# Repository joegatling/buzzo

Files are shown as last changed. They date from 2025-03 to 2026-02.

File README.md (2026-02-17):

# Buzzo

Buzzo Hero Image
Buzzo is a DIY open source set of game show buttons.

# Making A Buzzo Set
For instructions on how to build your own Buzzo can be found [here](/docs/Button_Assembly.md).

# How to Use
Buzzo is a set of buttons for running a fast paced answering game. Each contestant can hit their button to "buzz in". The system will queue up buttons in the order in which they buzzed. Each button is then given 30 seconds to provide an answer. With a set of Buzzo buttons, a standard game of _Trivial Pursuit_ can be turned into an exciting gameshow. 

Buzzo uses a wireless technology called ESP-Now. This allows them to communicate without the need for an existing WiFi network. However, only one Buzzo set can be operating in an area at a time, as all devices will try to communicate to any available controlelr that they can find.

## Buzzo Button

### Power
- Press the button on the Buzzo to turn it on. 
- Press and hold to turn it off.

A Buzzo Button will switch off automatically if left idle for a few minutes.

### Answering
To answer a question, press the button.  This will add the button into a queue, and each button will have 30 seconds to answer before moving to the next button in the queue.
If the timer expires, the device turns **red** and the button cannot be buzzed until the controller resets the round.

When it is a particular Buzzo's turn to answer, the button will light up yellow. As the timer expires, wedges of the button will go dark. Once they are all dark, the turn is over.

Buzzo devices that are in the answer queue will show a blue light. The number of bright wedges indicates device's place in the queue (eg, one bright wedge means 1st in the queue, two bright wedges means 2nd, etc...).

### Scoring
Each button will automatically keep track of correct answers, and display them as wedges on the button. Once a device has accumulated 6 correct answers, it has won.

## Buzzo Controller
The controller has four buttons:

`↺`/`⏻` - Power and Reset  
`⛌` - Incorrect  
`✓` - Correct  
`⃦`- Pause  

### Power
- Press this to turn on the device
- If the device is already powered on, press this to reset current round. This cleares

The Buzzo Controller will switch of automatically afer 15 minutes if there are devices connected, or after 2 minutes if nothing is connected.  
**WARNING: The Buzzo Controller is responsible for keeping track of scores. If it powers off, all devices will reset their score.**

### Judging Questions
If a Buzzo Button is answering, press the button marked `⛌` to judge the answer **incorrect**. Use `✓` to mark the answer as **correct**.
If a previously judged answer needs to be changed, press and hold either `⛌` or `✓`. This will retroactively change the last response.

### Pausing the Countdown
If for any reason the answering countdown needs to be paused (eg, if there is a dispute over a response, or an interruption to play), then hold the pause button. For as long as the button is held, the timer will be paused.

### Reseting
Press the `↺` button to reset the round. This will clear the answer queue, and reset all buttons so that they are ready for the next question.  
After resetting a round, the `↺` button can be pressed and held in order to reset the entire game. This will reset all the scores on all buttons.
Finally, after resetting around the `↺` button can be pressed and held once more to turn off the controller and all devices.

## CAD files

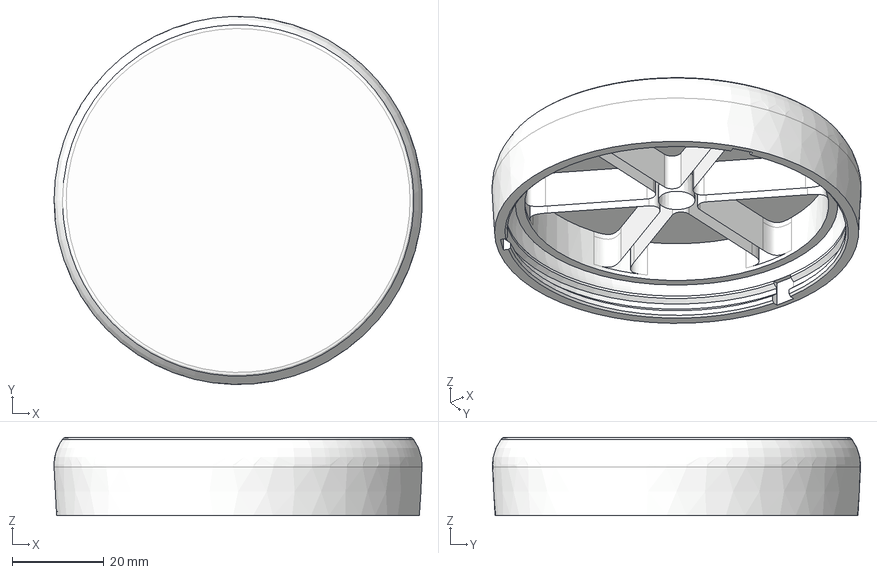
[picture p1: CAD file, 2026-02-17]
3d/Button/Button_ButtonCap_TPU.step
80.1 x 80.1 x 17.0 mm

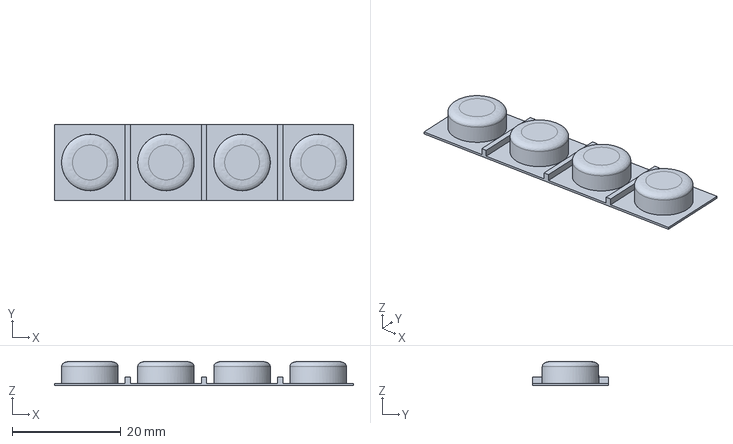
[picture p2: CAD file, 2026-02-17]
3d/Controller/Controller_ButtonCaps_TPU.step
55.0 x 14.0 x 4.50 mm

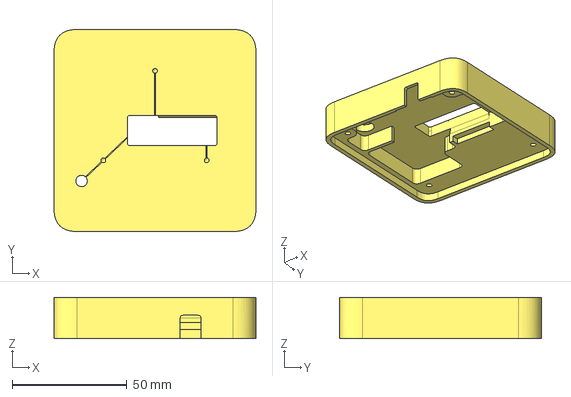
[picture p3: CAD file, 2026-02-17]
3d/Button/Button_Base.step
88.0 x 88.0 x 18.0 mm

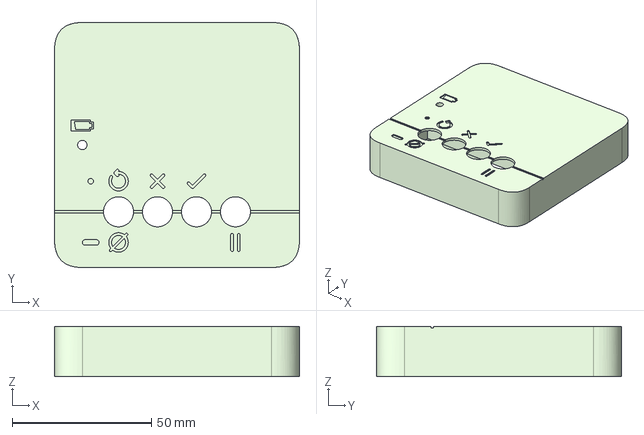
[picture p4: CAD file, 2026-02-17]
3d/Controller/Controller_Base.step
88.0 x 88.0 x 18.0 mm

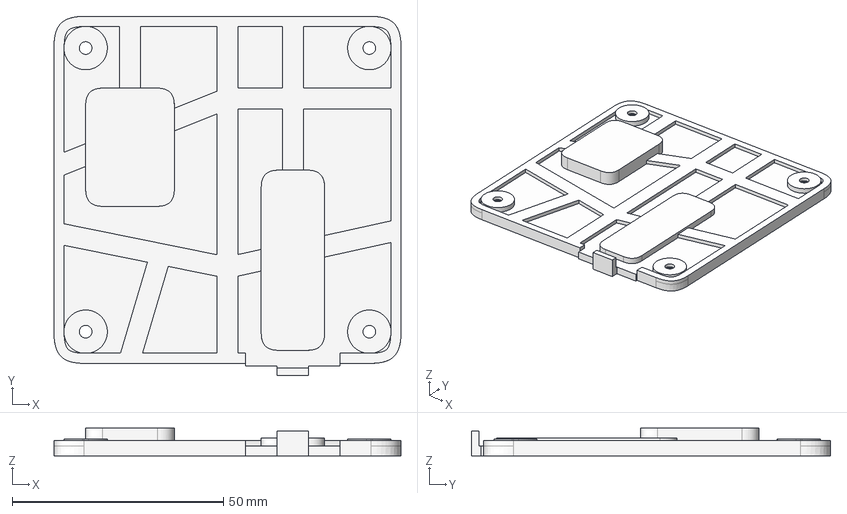
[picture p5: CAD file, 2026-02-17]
3d/Button/Button_Bottom.step
82.2 x 85.1 x 6.60 mm

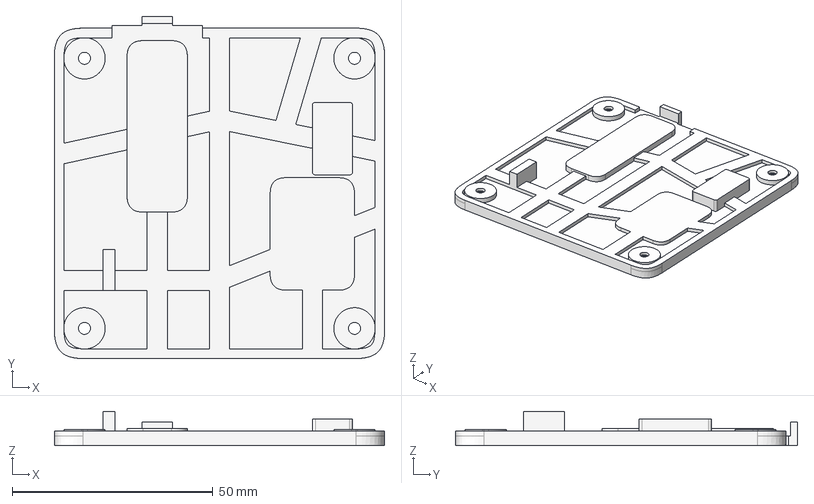
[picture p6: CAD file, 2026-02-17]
3d/Controller/Controller_Bottom.step
82.2 x 85.1 x 8.48 mm

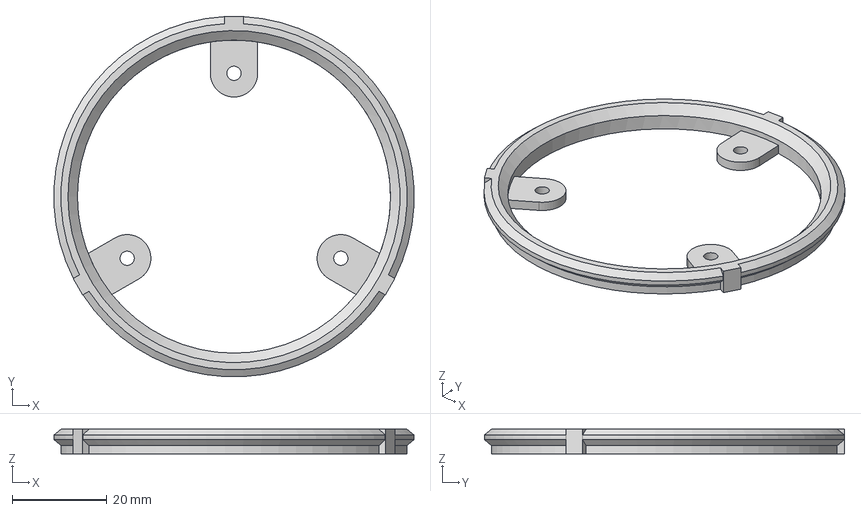
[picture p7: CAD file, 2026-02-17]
3d/Button/Button_Collar.step
75.9 x 75.9 x 5.23 mm

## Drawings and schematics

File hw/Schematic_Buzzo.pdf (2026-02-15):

Button - LEDs | Button - Connections

## GND

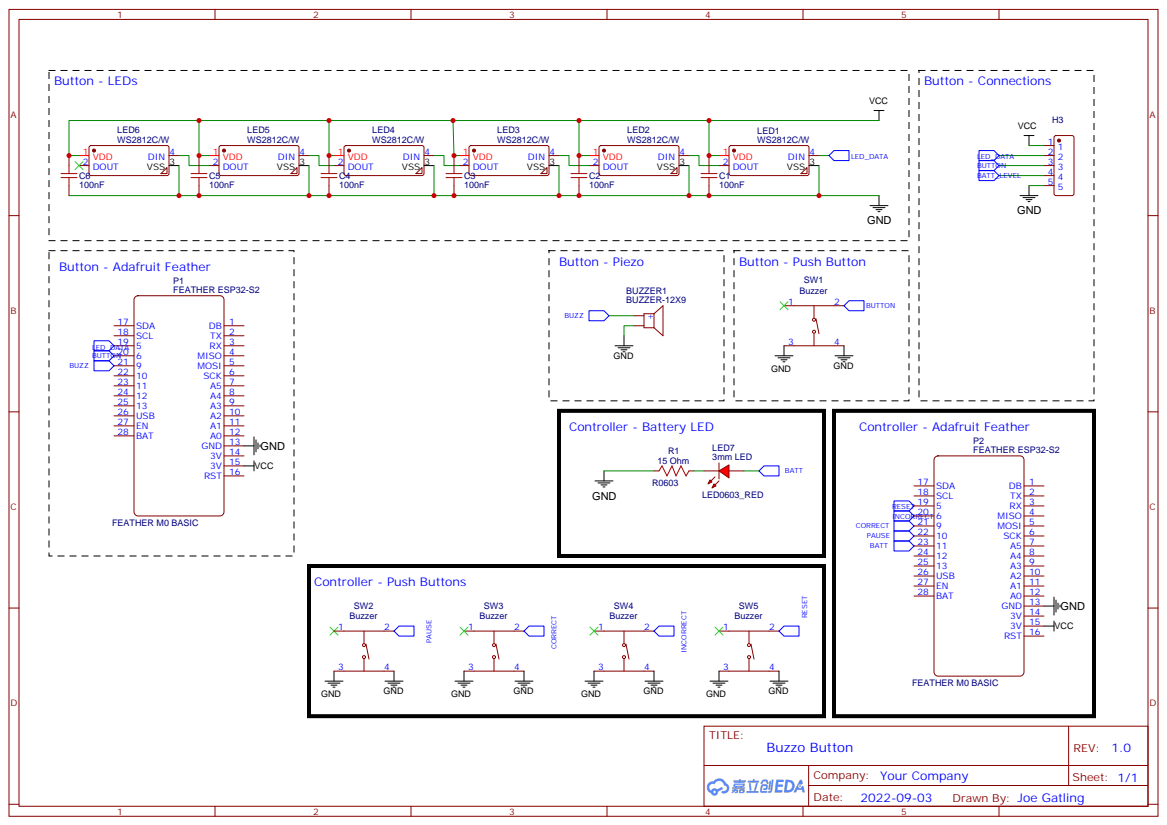
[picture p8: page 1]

Drawn By: Joe Gatling

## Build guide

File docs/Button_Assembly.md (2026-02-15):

# Making a Buzzo

Here's a basic guide for building a Buzzo. 

## Making the Buzzo Button

## Step 1 - Gather the parts
A single Buzzo Button requires...

- 1x Assembled Buzzo LED ring PCB (See step 2)
- 3D printed parts (See Step 3)
- 1x Adafruit ESP32-S3 Feather dev board (https://www.adafruit.com/product/5477)
- 1x 9mm Piezeo Buzzer (https://www.amazon.com/dp/B0827DS4HH)
- 1x 500mAh Lithium Ion Battery (https://www.adafruit.com/product/1578)
- 1x 10mm (tall) x 12mm x 12mm tactile switch (https://www.lcsc.com/product-detail/C127505.html)
- 7x M2x10mm screws
- Wire

## Step 2 - Ordering the PCBs
The main component of the Buzzo Button is a custom LED ring PCB. The gerber files can be found [here](/hw/). My initial run of PCBs were ordered from JLCPCB.com.
The LED ring PCB.

## Step 3 - 3D Print the Parts

All the STEP files for 3D printing can be found [here](/3d/Button/). Most of the parts can be printed out of any kind of PLA but the part `Button_ButtonCap_TPU.step` needs to be printed in white TPU as it needs to be flexible and diffuse light.

## Step 4 - Assemble the wiring
The wiring is quite simple. Connect everything up as follows:

- Feather `3V` ↔ `3.3v` on Ring PCB
- Feather `GND` ↔ `GND` on Ring PCB
- Feather `Pin 5` ↔ `LED` on Ring PCB
- Feather `Pin 6` ↔ `BTN` on Ring PCB
- Feather `Pin 9` ↔ Piezo Pin A (This component has no polarity)
- Feather `GND` ↔ Piezo Pin B (Or `GND` on the Ring PCB)

Example completed Buzzo wiring

All the wiring can be done before assembling the 3D printed parts. Below is what a partially assembled device looks like. 

Some tips:
- Feed the assembled wiring in through the top by sliding the Feather through the hole.
- Note that the LED PCB sits on top of the printed collar piece.
- A small blob of hot glue can be used to hold the piezo speaker in place.

Buzzo button top
Buzzo button top

## Step 5 - Upload the firmware
The firmware is written in C++, and is crea

1. Clone this repo to your computer
2. Install Visual Studio Code
3. Inside Visual Studio Code, install the PlatformIO Add-on
4. Open the project in Visual Studio Code, and set the environment to **buzzo_button_adafruit_USBc**.
5. Plug in your assembled Buzzo Button
6. Click **->** (PlatformIO: Upload)

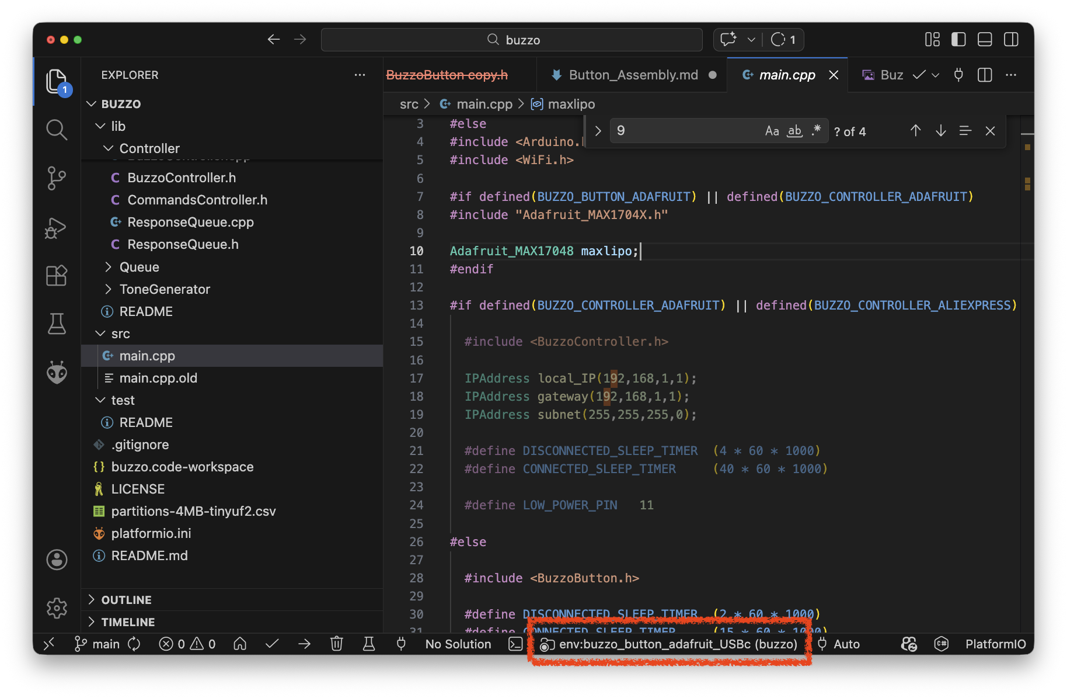
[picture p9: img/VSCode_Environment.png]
Visual studio code environment

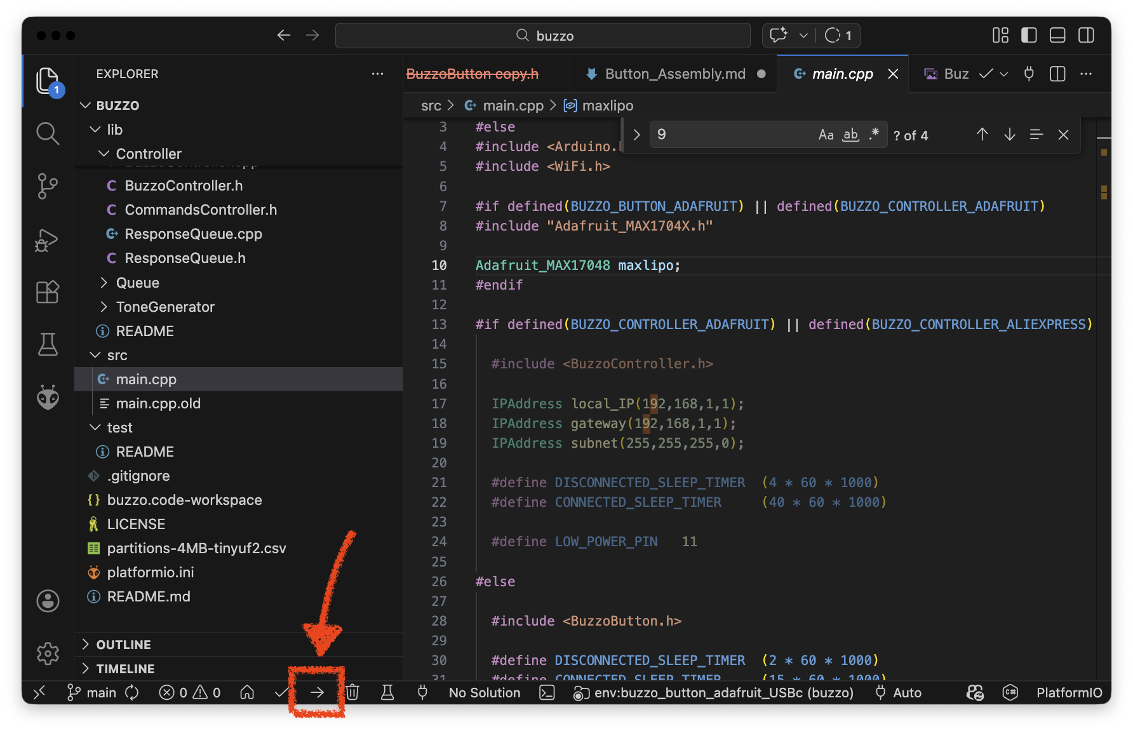
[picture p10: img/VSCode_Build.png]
Visual studio code environment


# Making the Buzzo Controller

## Step 1 - Gather the parts
A single Buzzo Controller requires...

- Some kind of button PCB (See Step 2)
- 3D printed parts (See Step 3)
- 1x Adafruit ESP32-S3 Feather dev board (https://www.adafruit.com/product/5477)
- 1x 500mAh Lithium Ion Battery (https://www.adafruit.com/product/1578)
- 4x M2x10mm screws
- 1x 3mm LED
- 1x Resistor, (value depending on the LED forward voltage)
- 4x Tactile Switches (Specifics unknown, see step 2)
- Wire

## Step 2 - PCB Sidequest
This is where the instructions get murky. Since the Buzzo Controller is still an early prototype, there is actually no PCB designed for it. All existing version were built using a scavanged PCB. Below is a reference of what the PCB looked like. Designing something that fits that shape would allow the existing 3D printable models to be used.

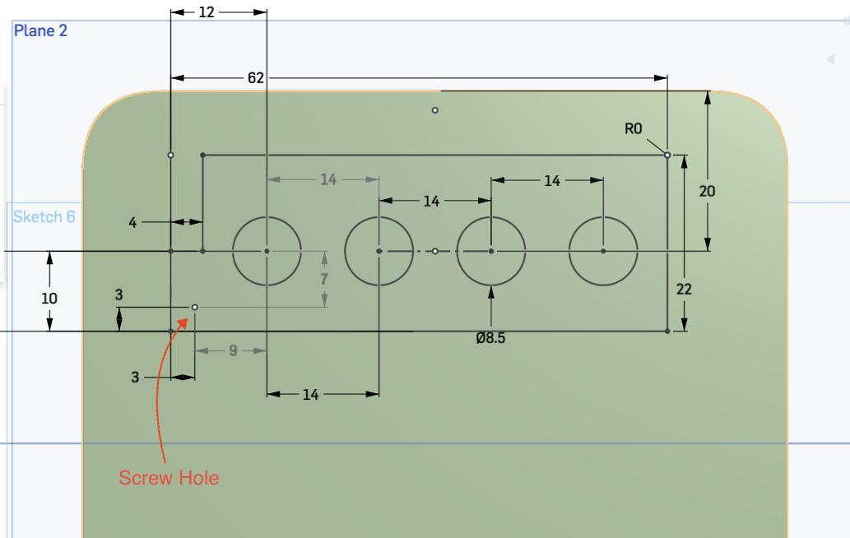
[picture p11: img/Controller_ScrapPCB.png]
Buzzo Controller PCB


You can see the scrap PCB in the assembled photo below.

## Step 3 - The Wiring

- Feather `Pin 5` ↔ Reset Button (Other pin on switch to GND)
- Feather `Pin 6` ↔ Incorrect Button (Other pin on switch to GND)
- Feather `Pin 9` ↔ Correct Button (Other pin on switch to GND)
- Feather `Pin 10` ↔ Pause Button (Other pin on switch to GND)
- Feather `Pin 11` ↔ Resistor ↔ LED ↔ GND

Assembled Buzzo Controller

## Step 4 - Upload the firmware
The firmware is written in C++, and is crea

1. Clone this repo to your computer
2. Install Visual Studio Code
3. Inside Visual Studio Code, install the PlatformIO Add-on
4. Open the project in Visual Studio Code, and set the environment to **buzzo_controller_adafruit_USBc**.
5. Plug in your assembled Buzzo Controller
6. Click **->** (PlatformIO: Upload)

Visual studio code environment

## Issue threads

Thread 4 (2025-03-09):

BUG - If an incorrect client powers off, they get to take another turn.

joegatling, 2025-03-09:
Controller needs to retain that the client has answered incorrectly, even if they are disconnected.

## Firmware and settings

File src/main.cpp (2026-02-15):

#if defined(NATIVE_TEST)

#else
#include <Arduino.h>
#include <WiFi.h>

#if defined(BUZZO_BUTTON_ADAFRUIT) || defined(BUZZO_CONTROLLER_ADAFRUIT)
#include "Adafruit_MAX1704X.h"

Adafruit_MAX17048 maxlipo;
#endif

#if defined(BUZZO_CONTROLLER_ADAFRUIT) || defined(BUZZO_CONTROLLER_ALIEXPRESS)

  #include <BuzzoController.h>

  IPAddress local_IP(192,168,1,1);
  IPAddress gateway(192,168,1,1);
  IPAddress subnet(255,255,255,0);  

  #define DISCONNECTED_SLEEP_TIMER  (4 * 60 * 1000)
  #define CONNECTED_SLEEP_TIMER     (40 * 60 * 1000)

  #define LOW_POWER_PIN   11

#else

  #include <BuzzoButton.h>

  #define DISCONNECTED_SLEEP_TIMER  (2 * 60 * 1000)
  #define CONNECTED_SLEEP_TIMER     (15 * 60 * 1000)

#endif


// const char* ssid     = "Trivia Computer Access Point";
// const char* password = "123456789";

#define LED_PIN 13

#define RANGE_START 39
#define RANGE_END 40

#define BATTERY_MAX 4.2f
#define BATTERY_MIN 3.3f

//bool isConnected = false;
//unsigned long lastConnectionCheckTime = 0;

unsigned long wakeTime = 0;

unsigned long batteryReportInterval = 0;
unsigned long lastClientReportTime = 0;

float mapFloat(float x, float in_min, float in_max, float out_min, float out_max) 
{
  if(in_max == in_min)
  {
    return out_min;
  }
  return (x - in_min) * (out_max - out_min) / (in_max - in_min) + out_min;
}

unsigned int GetBatteryLevel()
{
  #if defined(BUZZO_BUTTON_ADAFRUIT) || defined(BUZZO_CONTROLLER_ADAFRUIT)
    float cellVoltage = maxlipo.cellVoltage();
    if (isnan(cellVoltage)) 
    {
      Serial.println("Failed to read cell voltage, check battery is connected!");
      delay(2000);
      return 100;
    }
    return (int)maxlipo.cellPercent();
  #else
    int sensorValue = analogReadMilliVolts(BATT_MONITOR);
    sensorValue *= 2;
    float voltage = sensorValue / 1000.0f;

    float batteryPercentage = mapFloat(voltage, BATTERY_MIN, BATTERY_MAX, 0.0, 100.0);    

    batteryPercentage = max(0.0f, batteryPercentage);
    batteryPercentage = min(100.0f, batteryPercentage);

    // if(millis() - batteryReportInterval > 5000)
    // {
    //   batteryReportInterval = millis();
    //   Serial.print("Battery: ");
    //   Serial.print(voltage);
    //   Serial.print("v (");
    //   Serial.print(batteryPercentage);    
    //   Serial.println("%)");
    // }

    return (unsigned int)batteryPercentage;
  #endif
}

void Sleep()
{
    #if BUZZO_BUTTON
      BuzzoButton::GetInstance()->SetState(BuzzoButton::GO_TO_SLEEP);
      return;
    #else
      BuzzoController::GetInstance()->SetAllClientsToSleep();

      delay(50);

      WiFi.disconnect(true);
      digitalWrite(LED_PIN, LOW);
      delay(100);
      esp_sleep_enable_ext0_wakeup(GPIO_NUM_10, LOW);
      esp_deep_sleep_start();
    #endif


    // #if defined(BUZZO_BUTTON_ALIEXPRESS)
    //   esp_sleep_enable_ext0_wakeup(GPIO_NUM_32, LOW);
    // #elif defined(BUZZO_BUTTON_ADAFRUIT)
    //   esp_sleep_enable_ext0_wakeup(GPIO_NUM_6, LOW);
    // #endif    
}


void setup() 
{
  Serial.begin(115200);
  
  delay(200); // Give serial time to connect
  
  Serial.println();

  wakeTime = millis();

  #if defined(ESP32)  
    setCpuFrequencyMhz(80);
  #endif

  #if !defined(BUZZO_BUTTON_ALIEXPRESS)
    while (!maxlipo.begin()) {
      Serial.println(F("Couldnt find Adafruit MAX17048?\nMake sure a battery is plugged in!"));
      delay(2000);
    }
    Serial.print(F("Found MAX17048"));
    Serial.print(F(" with Chip ID: 0x")); 
    Serial.println(maxlipo.getChipID(), HEX);  
  #endif

  #if BUZZO_CONTROLLER

    pinMode(LOW_POWER_PIN, ANALOG);
    analogWrite(LOW_POWER_PIN, 64);
    
    pinMode(LED_PIN, OUTPUT);
    digitalWrite(LED_PIN, HIGH);
    
    BuzzoController::GetInstance()->Initialize();

    Serial.println("Buzzo Controller Initialized");
    
  #elif BUZZO_BUTTON

    digitalWrite(LED_PIN, HIGH);

    BuzzoButton::GetInstance()->Initialize();
    BuzzoButton::GetInstance()->SetState(BuzzoButton::DISCONNECTED);

    BuzzoButton::GetInstance()->SetBatteryLevel(GetBatteryLevel());
    BuzzoButton::GetInstance()->ShowBatteryLevelOnButton();

  #endif

}

#if BUZZO_CONTROLLER

void loop() 
{
  BuzzoController::GetInstance()->Update(); 

  unsigned long timeSinceWake = millis() - wakeTime;
  unsigned long idleTime = min(timeSinceWake, BuzzoController::GetInstance()->TimeSinceLastButtonPress());

  if(BuzzoController::GetInstance()->GetActiveClientCount() > 0)
  {
    if(idleTime > CONNECTED_SLEEP_TIMER)
    {
      Sleep();
    }    
  }
  else
  {
    if(idleTime > DISCONNECTED_SLEEP_TIMER)
    {
      Sleep();
    }
  }  

  if(BuzzoController::GetInstance()->IsGoingToSleep())
  {
    //Serial.println("Going to sleep");
    analogWrite(LOW_POWER_PIN, 0);
  }
  else if(GetBatteryLevel() < 10)
  {
    //Serial.println("Low battery");
    analogWrite(LOW_POWER_PIN, (millis() % 1000) < 500 ? 256 : 0);
  }
  else if(BuzzoController::GetInstance()->GetMinBatteryLevelForClients() < 10)
  {
    //Serial.println("Low client battery");
    analogWrite(LOW_POWER_PIN, (millis() % 2000) < 200 ? 10 : 0);
  }
  else
  {
    //Serial.println("Normal");
    analogWrite(LOW_POWER_PIN, 2);
  }

  if(GetBatteryLevel() < 2)
  {
    Sleep();
  }

  if(millis() - lastClientReportTime > 5000)
  {
    lastClientReportTime = millis();
    Serial.print("Controller Battery: ");
    Serial.println(GetBatteryLevel());
    Serial.print("Clients: ");
    Serial.println(BuzzoController::GetInstance()->GetActiveClientCount());
    if(BuzzoController::GetInstance()->GetActiveClientCount() > 0)
    {
      Serial.print("Min Client Battery: ");
      Serial.println(BuzzoController::GetInstance()->GetMinBatteryLevelForClients());
    }
  }

}

#elif BUZZO_BUTTON

void loop() 
{  
  
  if(BuzzoButton::GetInstance()->GetState() != BuzzoButton::NONE)
  {
    unsigned long timeSinceWake = millis() - wakeTime;
    unsigned long idleTime = min(timeSinceWake, BuzzoButton::GetInstance()->TimeSinceLastButtonPress());
    
    if(idleTime > CONNECTED_SLEEP_TIMER)
    {
      Sleep();
    }  
        
  }
  
  BuzzoButton::GetInstance()->SetBatteryLevel(GetBatteryLevel());
  BuzzoButton::GetInstance()->Update(); 

  if(GetBatteryLevel() < 2.0f)
  {
    Sleep();
  }

}


#endif
#endif

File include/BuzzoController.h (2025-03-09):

#pragma once

#include <string>
#include <WiFiudp.h>
#include <SimpleButton.h>

#include "ButtonClientInfo.h"
#include "ResponseQueue.h"

#define PACKET_MAX_SIZE 1024
#define MAX_CLIENTS 12

#define PORT 8888


#ifdef NEW_PINS
    // WHITE
    #define PAUSE_BUTTON_PIN 33
    // GREY
    #define CORRECT_BUTTON_PIN 15
    // PURPLE
    #define INCORRECT_BUTTON_PIN 32
    // BLUE
    #define RESET_BUTTON_PIN 14
#else
    #define PAUSE_BUTTON_PIN 33
    #define CORRECT_BUTTON_PIN 32
    #define INCORRECT_BUTTON_PIN 14
    #define RESET_BUTTON_PIN 15
#endif

class BuzzoController
{
    public:
        enum ControllerState
        {
            PLAYING,
            SETUP
        };

        static BuzzoController* GetInstance();
        void Initialize();
        void Update();


        void EndCurrentRespondantTurn(bool isCorrect);
        void BeginIncorrectButtonPress();
        void ResetButtonPress();      
        void HoldResetButton();  
        void ReleaseHoldResetButton();
        void ReleaseHoldIncorrectButton();

        void BeginPauseButtonPress();
        void EndPauseButtonPress();

        void AdjustPreviousRespondant(bool isCorrect);

        void SetAllClientsToSleep();

        unsigned long TimeSinceLastButtonPress() { return millis() - _lastButtonPressTime; } 

        int GetActiveClientCount();
        int GetActiveClientsYetToPlayCount();

        unsigned int GetMinBatteryLevelForClients();

    private:
        static BuzzoController* _instance;

        BuzzoController();

        void ProcessPacket();

        void ProcessRegisterCommand(IPAddress ip, std::string paramId, std::string paramBattery);
        void ProcessBuzzCommand(IPAddress ip);

        void SendAnswerCommand(IPAddress ip, int timer, int totalTime);
        void SendQueueCommand(IPAddress ip, int placeInQueue);
        void SendResponseCommand(IPAddress ip, bool isCorrect);
        void SendResetCommand(IPAddress ip, bool canBuzz);
        void SendSelectCommand(IPAddress ip);
        void SendErrorCommand(IPAddress ip, int errorCode);
        void SendScoreCommand(IPAddress ip, int score);
        void SendSleepCommand(IPAddress ip);

        void UpdatePlaying();
        void UpdateSetup();

        void AddAllRemainingClientsToQueue();
        
        void AddClient(ButtonClientInfo* newClient);
        void RemoveClientAt(unsigned int index);
        ButtonClientInfo* GetClient(IPAddress ip);
        ButtonClientInfo* GetClient(std::string id);

        


        ButtonClientInfo* _clients[MAX_CLIENTS];
        unsigned int _clientCount = 0;

        char packetBuffer[PACKET_MAX_SIZE + 1]; 

        WiFiUDP udp;

        unsigned long _lastSendTime = 0;
        unsigned long _responseStartTime = 0;
        unsigned long _nextResponderDelayStartTime = 0;
        unsigned long _lastRespondantPingTime = 0;
        unsigned long _lastButtonPressTime = 0;
        unsigned long _responsePauseTime = 0;
        unsigned long _lastMillis = 0;

        unsigned long _autoResestTime = 0;

        bool _isAcceptingResponses = true;
        bool _isReset = false;
        bool _shouldSleep = false;
        bool _isInAdjustMode = false;
        bool _isPaused = false;

        ControllerState _currentState = BuzzoController::PLAYING;

        SimpleButton _correctButton;
        SimpleButton _incorrectButton;
        SimpleButton _resetButton;
        SimpleButton _pauseButton;

        ResponseQueue<std::string> _responseQueue;
        std::string _currentRespondant;
        std::string _previousRespondant;
        bool _previousRespondantWasCorrect = false;

        std::string _participants[MAX_CLIENTS];
        unsigned int _participantCount;

};

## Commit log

2022-08-28 Lots of (probably broken updates)
    [BuzzoButton.cpp, BuzzoButton.h, BuzzoController.h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]
2022-09-03 Button logic
2022-09-12 Correct, Incorrect, and Victory states
    [BuzzoButton.cpp, BuzzoButton.h, main.cpp]
2022-09-22 Changed how the button handles wifi disconnect
2022-09-25 Changed the way time remaining is communicated between controller and button
2022-10-02 Sleep mode for button
2023-12-29 A few updates
    Controller:
    - Battery monitor code
    - Pause functionality
    - Disabled settings mode
    Button:
    - Battery monitor code
    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
2025-02-23 Improved battery management
2025-03-01 Fixed a divide by zero in the tone generator
    [BuzzoButton.cpp, ToneGenerator.cpp, main.cpp]
2025-03-06 Fixed the Adafruit microcontroller
    [BuzzoButton.cpp, BuzzoButton.h, ToneGenerator.cpp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]
2025-03-09 Fixed the sleep issue for the adafruit variant
    [BuzzoButton.cpp, BuzzoButton.h, ToneGenerator.cpp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]
2025-03-23 Gerber File and Schematic
2025-04-06 Got things working again
    [partitions-4MB-tinyuf2.csv]
2025-06-07 fixed controller sleep issue
    [main.cpp]
2026-02-15 Added 3D Print files
    [Button_Base.step, Button_Bottom.step, Button_ButtonCap_TPU.step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]
2026-02-15 Updates to 3d models
    [Button_Bottom.step, Controller_Bottom.step]
2026-02-15 Updated schematic
2026-02-15 Assembly instructions WIP
2026-02-15 Add M2x10mm screws to component lists
    Added screws to the list of required components for both the Buzzo Controller and the main project.
2026-02-15 Create Button Assembly guide for Buzzo
    Added a basic guide for building a Buzzo, including PCB ordering information and required parts.
2026-02-15 Revise Button Assembly documentation with detailed steps
    Updated the Button Assembly guide with detailed steps for gathering parts, ordering PCBs, 3D printing, wiring assembly, and uploading firmware.
2026-02-15 Update Button Assembly guide for clarity and formatting
2026-02-15 Enhance Buzzo Button assembly instructions
    Added additional tips for assembling the Buzzo Button and clarified wiring instructions.
2026-02-15 Reference for scrap pcb
2026-02-15 Enhance Buzzo assembly guide with detailed steps
    Expanded the guide for building a Buzzo, including detailed steps for assembling the button and controller, gathering parts, and uploading firmware.
2026-02-15 Revise Button Assembly documentation
    Updated the Button Assembly guide with additional details and images for clarity.
2026-02-15 Enhance README with usage instructions for Buzzo
    Expanded instructions for using Buzzo buttons and controller, including power, answering, scoring, and judging questions.
2026-02-15 Improve formatting of controller button descriptions
    Formatted button descriptions for clarity.
2026-02-15 Update README with Buzzo Controller button details
2026-02-16 Enhance README with Buzzo button usage details
    Added description of Buzzo buttons and their functionality.
2026-02-17 Fixed some issues with the 3d models
    [Button_Base.step, Button_Bottom.step, Button_ButtonCap_TPU.step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]
